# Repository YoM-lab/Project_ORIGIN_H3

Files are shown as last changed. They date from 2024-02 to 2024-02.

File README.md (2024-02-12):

## Project-ORIGIN_H3


## 项目简介
> 小up是一个开发板兴趣爱好者:-)，市面上绝大部分Linux开发板都是没有小巧屏幕的，而且设计闭源不能随心所欲的更改，只是买回来玩并不能深刻理解，引用费曼所说：“What I cannot create，I do not understand”，结合网上的开源方案，所以就有了想自己制作的想法，一来是想熟悉Allegro软件，二来是巩固Linux驱动开发。现在发布出来供后来人参考，同时也参考一些开源社区和UP主，后面会一一列出。硬件在23年5月份完成，由于up是一个学生，制作过程全部自费，所以采用了四层板，对于初学者走线非常痛苦:-(；软件在23年9月份完成，由于研二阶段太忙了，一直到现在才正式发出来:-)
>
> 项目在硬件上包括了1.14寸显示屏、麦克风、音频、HDMI、WIFI、MIPI摄像头(未驱动成功，非必须)，基本上可以实现一个卡片电脑的功能。

**项目制作流程**：[【自制】开源四核A7卡片电脑，从规划到实物软硬件开发，拥有自己的小电脑](https://www.bilibili.com/video/BV1XW421P7bK/?share_source=copy_web&vd_source=7833e202419e0abc2ac3d27a5c3fbd21)

## 硬件部分

* 硬件设计全部在**1_Hardware**文件夹
* 设计使用的**软件是Allegro，而不是AD！！！**在**1_Hardware**文件夹内给出了原理图
* 焊接使用了**加热台、热风枪、低温焊锡膏、钢网**
* 由于up只进行了一次打板（自费），在后期难免的遇到了一些问题，大部分都是因为板层不够多（四层）导致的，**但不影响第一板的正常运行**。up时间有限，未能作出更改，如果有后来者复刻，可以上六层板，进一步缩小体积，方便布线，项目硬件上可改进之处参考**1_Hardware/README.md**文件
## 软件部分

* **Uboot**
	
	* 在**2_Uboot**文件夹内
	* Uboot适配的是全志官方支线，没有做出太多修改
* **Linux**
	* 在**3_Linux**文件夹内
	* 内核是自己适配4.14.111内核，也可采用第三方内核（国内开发板厂商）
* **Rootfs** 
	* 在**4_Rootfs**文件夹内
	
	* 根文件系统是自己移植的ubuntu16.04， 也可采用第三方根文件系统（国内开发板厂商）
* 编译方法可以参考教程：[Building U-boot and Linux for H5/H3/H2+/zh - FriendlyELEC WiKi](https://wiki.friendlyelec.com/wiki/index.php/Building_U-boot_and_Linux_for_H5/H3/H2+/zh)
* 由于Github不能上传大文件，所以请大家通过百度云下载:-(

## 烧录镜像
* 烧录SD镜像在**5_Images**文件夹内
* Ubuntu16.04为个人制作的镜像，用户名：pi，密码：pi，root密码：oh3
* Debian 8为第三方镜像，参考连接：[NanoPi M1 Plus/zh - FriendlyELEC WiKi](https://wiki.friendlyelec.com/wiki/index.php/NanoPi_M1_Plus/zh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)
## 驱动部分

* Linux简单的驱动移植在7_Drivers文件夹内，在up本人学习时编写的，把ORIGIN_H3当成一个小型的开发板:-)
* MPU6050驱动在21_I2C文件夹内
* 驱动编写参考：[i.MX6ULL Linux阿尔法开发板 — 正点原子资料下载中心 1.0.0 文档 (openedv.com)](http://www.openedv.com/docs/boards/arm-linux/zdyz-i.mx6ull.html)

## 参考链接

* [NanoPi M1 Plus/zh - FriendlyELEC WiKi](https://wiki.friendlyelec.com/wiki/index.php/NanoPi_M1_Plus/zh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)
* [orangepi-xunlong (Orange Pi) (github.com)](https://github.com/orangepi-xunlong)
*  [OSHW\] Yuzuki Chameleon is a Raspberry Pi A Shaped SBC based on Allwinner H616 (github.com)](https://github.com/YuzukiHD/YuzukiChameleon)
* [peng-zhihui/Project-Quantum: 超迷你模块化卡片电脑计划 (github.com)](https://github.com/peng-zhihui/Project-Quantum)
* [小白自制Linux开发板(F1C200s)整理系列，持续更新中 / 全志 SOC / WhyCan Forum(哇酷开发者社区)](https://whycan.com/t_7275.html)
* [i.MX6ULL Linux阿尔法开发板 — 正点原子资料下载中心 1.0.0 文档 (openedv.com)](http://www.openedv.com/docs/boards/arm-linux/zdyz-i.mx6ull.html)

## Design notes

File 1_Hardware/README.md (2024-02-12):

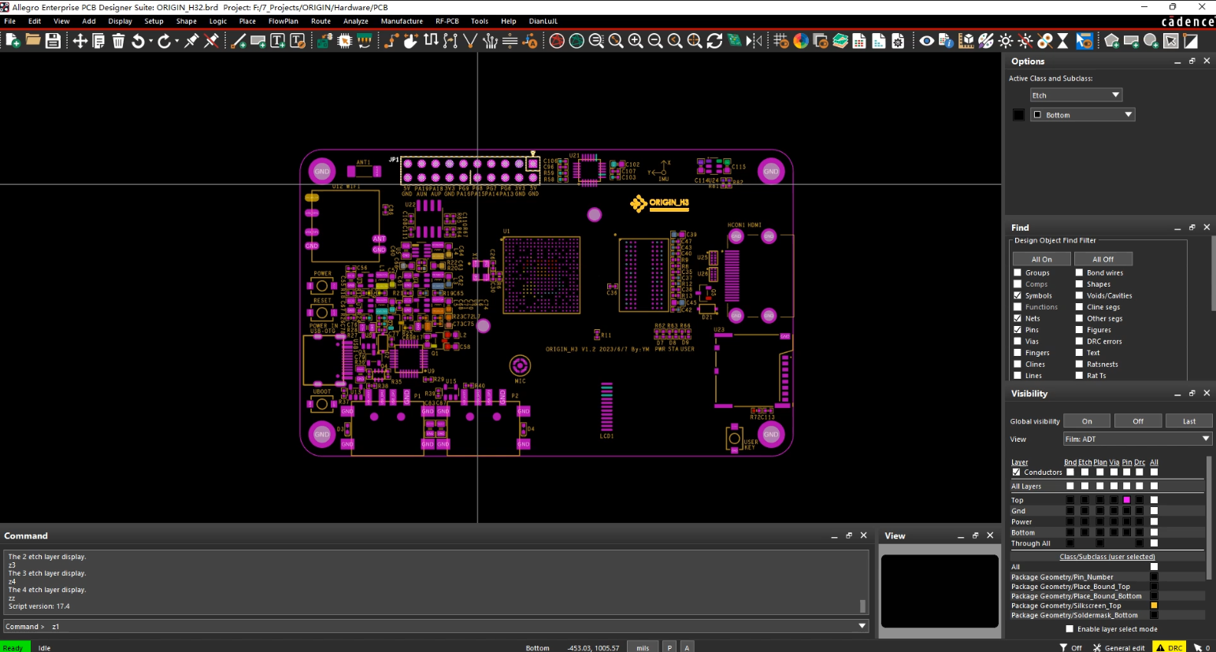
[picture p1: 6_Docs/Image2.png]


## ORIGIN_H3

* 硬件采用Allegro软件设计(Capture CIS 17.4 + PCB Editor 17.4)，使用相同及以上版本即可打开。
## Garber文件
* 电路板打样需要使用到Garber文件，已经导出在__ORIGIN_H3_Garber.rar__文件内。
## Allegro软件安装参考
[阿狸狗破戒大师 | 吴川斌的博客 (mr-wu.cn)](http://aligou.mr-wu.cn/)。
## 硬件优化
由于up只进行了一次打板（自费），在后期难免的遇到了一些问题，大部分都是因为板层不够多（四层）导致的，**但不影响第一板的正常运行**。up时间有限，未能作出更改，如果有后来者复刻，可以上六层板，进一步缩小体积，方便布线，项目硬件上可改进之处列在下面：
  * IMU丝印错误
  * USB封装有误
  * HDMI未进行等长布线
  * 摄像头接口电路有误（视频中使用的是USB摄像头）
  * MIC走线未包地处理
  * 音频输出电路走线未包地处理
  * 丝印C44和C41电容接触过近
  * 原理图中U13、U14芯片SY6280为USB限流芯片，可以直接将EN引脚接VCC，若未修改直接打板，需要使用磁阻或0欧姆电阻直接将输入和输出短接：


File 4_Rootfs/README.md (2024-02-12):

## ORIGIN_H3-Rootfs

## Ubuntu 16.04

* 系统打包成SD卡烧录镜像教程参考：[friendlyarm/sd-fuse_h3 (github.com)](https://github.com/friendlyarm/sd-fuse_h3)

* 百度云下载地址：

  链接：https://pan.baidu.com/s/1aDvAWxIi5sTljFk5ktj55g?pwd=2j3l 
  提取码：2j3l

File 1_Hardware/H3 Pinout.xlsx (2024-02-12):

PIN | Function |  | PIN | Function |  |  | PIN | PIN |  |  | PIN | Function |  | PIN |  |  | PIN
PA0 | UART2_TX | UART2 | PC0 | SPI0_MOSI | LCD_SDA | LCD | PD0 | PE0 | CAM | CAM | PF0 | SDC0_D1 | TF | PG0 |  |  | PL0
PA1 | UART2_RX |  | PC1 |  |  |  | PD1 | PE1 | CAM |  | PF1 | SDC0_D0 |  | PG1 |  |  | PL1
PA2 |  |  | PC2 | SPI0_CLK | LCD_SCL |  | PD2 | PE2 | CAM |  | PF2 | SDC0_CLK |  | PG2 | KYE | KEY | PL2
PA3 |  |  | PC3 | SPI0_CS | LCD_CS |  | PD3 | PE3 | CAM |  | PF3 | SDC0_CMD |  | PG3 | KEY |  | PL3
PA4 | UART0_TX | DEBUG | PC4 | I/O | LCD_RS |  | PD4 | PE4 | CAM |  | PF4 | SDC0_D3 |  | PG4 | KEY |  | PL4 | GPIO | RECOVERY
PA5 | UART0_RX |  | PC5 | I/O | LCD_RES |  | PD5 | PE5 | CAM |  | PF5 | SDC0_D2 |  | PG5 |  |  | PL5 | GPIO | VCC-IO-EN
PA6 |  |  | PC6 |  |  |  | PD6 | PE6 | CAM |  | PF6 | SDC0_DET |  | PG6 | UART1_TX | UART | PL6
PA7 |  |  | PC7 |  |  |  | PD7 | PE7 | CAM |  |  |  |  | PG7 | UART1_RX |  | PL7 | GPIO | WIFI_EN
PA8 | MPU6050-INT | MPU6050 | PC8 |  |  |  | PD8 | PE8 | CAM |  |  |  |  | PG8 | UART1_RTS |  | PL8 | GIPO | PWR_STB
PA9 | USER | LED | PC9 |  |  |  | PD9 | PE9 | CAM |  |  |  |  | PG9 | UART1_CTS |  | PL9 | GPIO | PWR_DRAM
PA10 | STATUS |  | PC10 |  |  |  | PD10 | PE10 | CAM |  |  |  |  | PG10 |  |  | PL10 | GPIO | PWR_LED
PA11 | I2C_SCK | MPU6050 | PC11 |  |  |  | PD11 | PE11 | CAM |  |  |  |  | PG11 |  |  | PL11
PA12 | I2C_SDA |  | PC12 |  |  |  | PD12 | PE12 | CAM |  |  |  |  | PG12 | PG12/USB0-OTGID | OTG
PA13 | SPI1_CS | SPI1 | PC13 |  |  |  | PD13 | PE13 | CAM |  |  |  |  | PG13
PA14 | SPI1_CLK |  | PC14 |  |  |  | PD14 | PE14 | GPIO
PA15 | SPI1_MOSI |  | PC15 |  |  |  | PD15 | PE15 | GPIO
PA16 | SPI1_MISO |  | PC16 |  |  |  | PD16
PA17 |  |  |  |  |  |  | PD17
PA18 | I2C_SCK | I2C1
PA19 | I2C_SDA
PA20
PA21
DRAM | LPDDR3 |  | HDMI | HDMI
USB0 | OTG |  | AUDIO | MIC | LINEOUT
USB1 | WIFI
USB2 | USB |  | RESET | RESET
USB3 | USB
 |  |  | UBOOT | UBOOT
 |  |  | CRYSTAL | CRYSTAL

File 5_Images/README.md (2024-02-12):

## ORIGIN_H3-Images

## Ubuntu 16.04

链接：https://pan.baidu.com/s/1Oyq-yipzldtNqOIcfeMQRg?pwd=ue1q 
提取码：ue1q 

## Debian

链接：https://pan.baidu.com/s/198FMZw4U8keiZBAOxm9Zbw?pwd=ifme 
提取码：ifme

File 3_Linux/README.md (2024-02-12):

## ORIGIN_H3-Linux

* 编译方法可以参考Friendlyelec的教程：[Building U-boot and Linux for H5/H3/H2+/zh - FriendlyELEC WiKi](https://wiki.friendlyelec.com/wiki/index.php/Building_U-boot_and_Linux_for_H5/H3/H2+/zh)

* 百度云下载地址：

  链接：https://pan.baidu.com/s/18vKWBYgACM9pWhj-3_hcDg?pwd=lwhe 
  提取码：lwhe

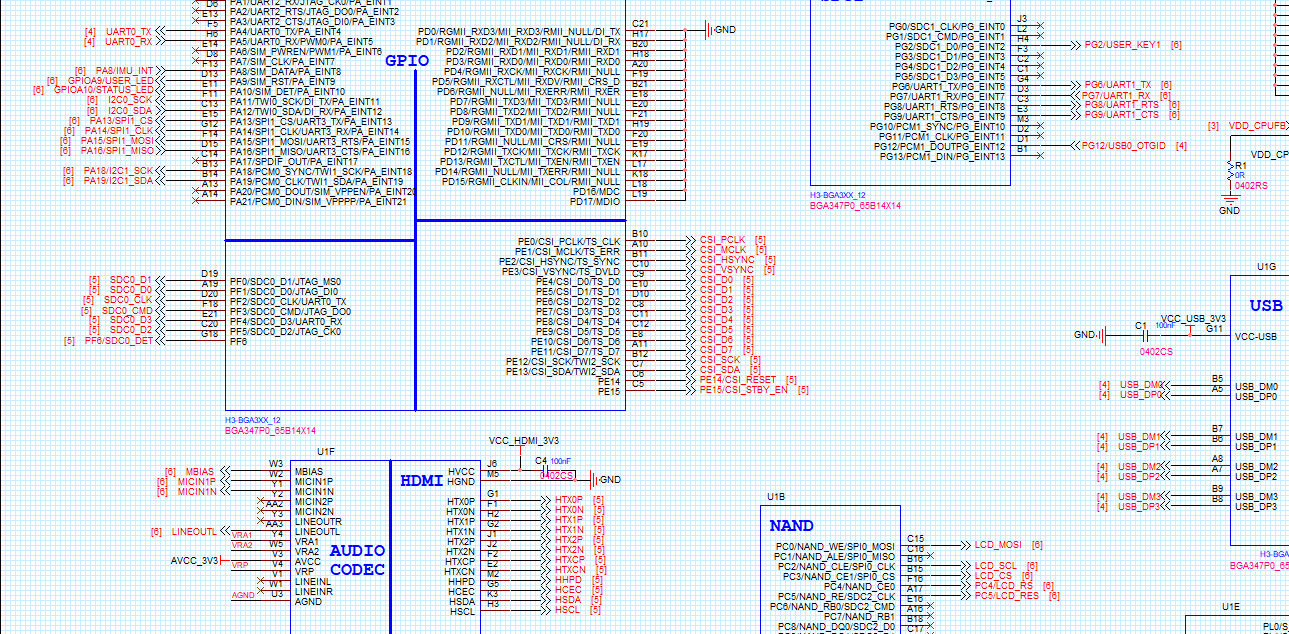
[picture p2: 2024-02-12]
1_Hardware/ORIGIN_H3.png

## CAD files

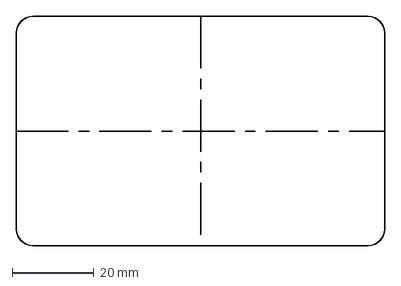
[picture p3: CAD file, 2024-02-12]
1_Hardware/origin_outline.DXF
90.0 x 56.0 mm

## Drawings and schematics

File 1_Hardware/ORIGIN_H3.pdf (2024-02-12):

# CPU

# GPIO

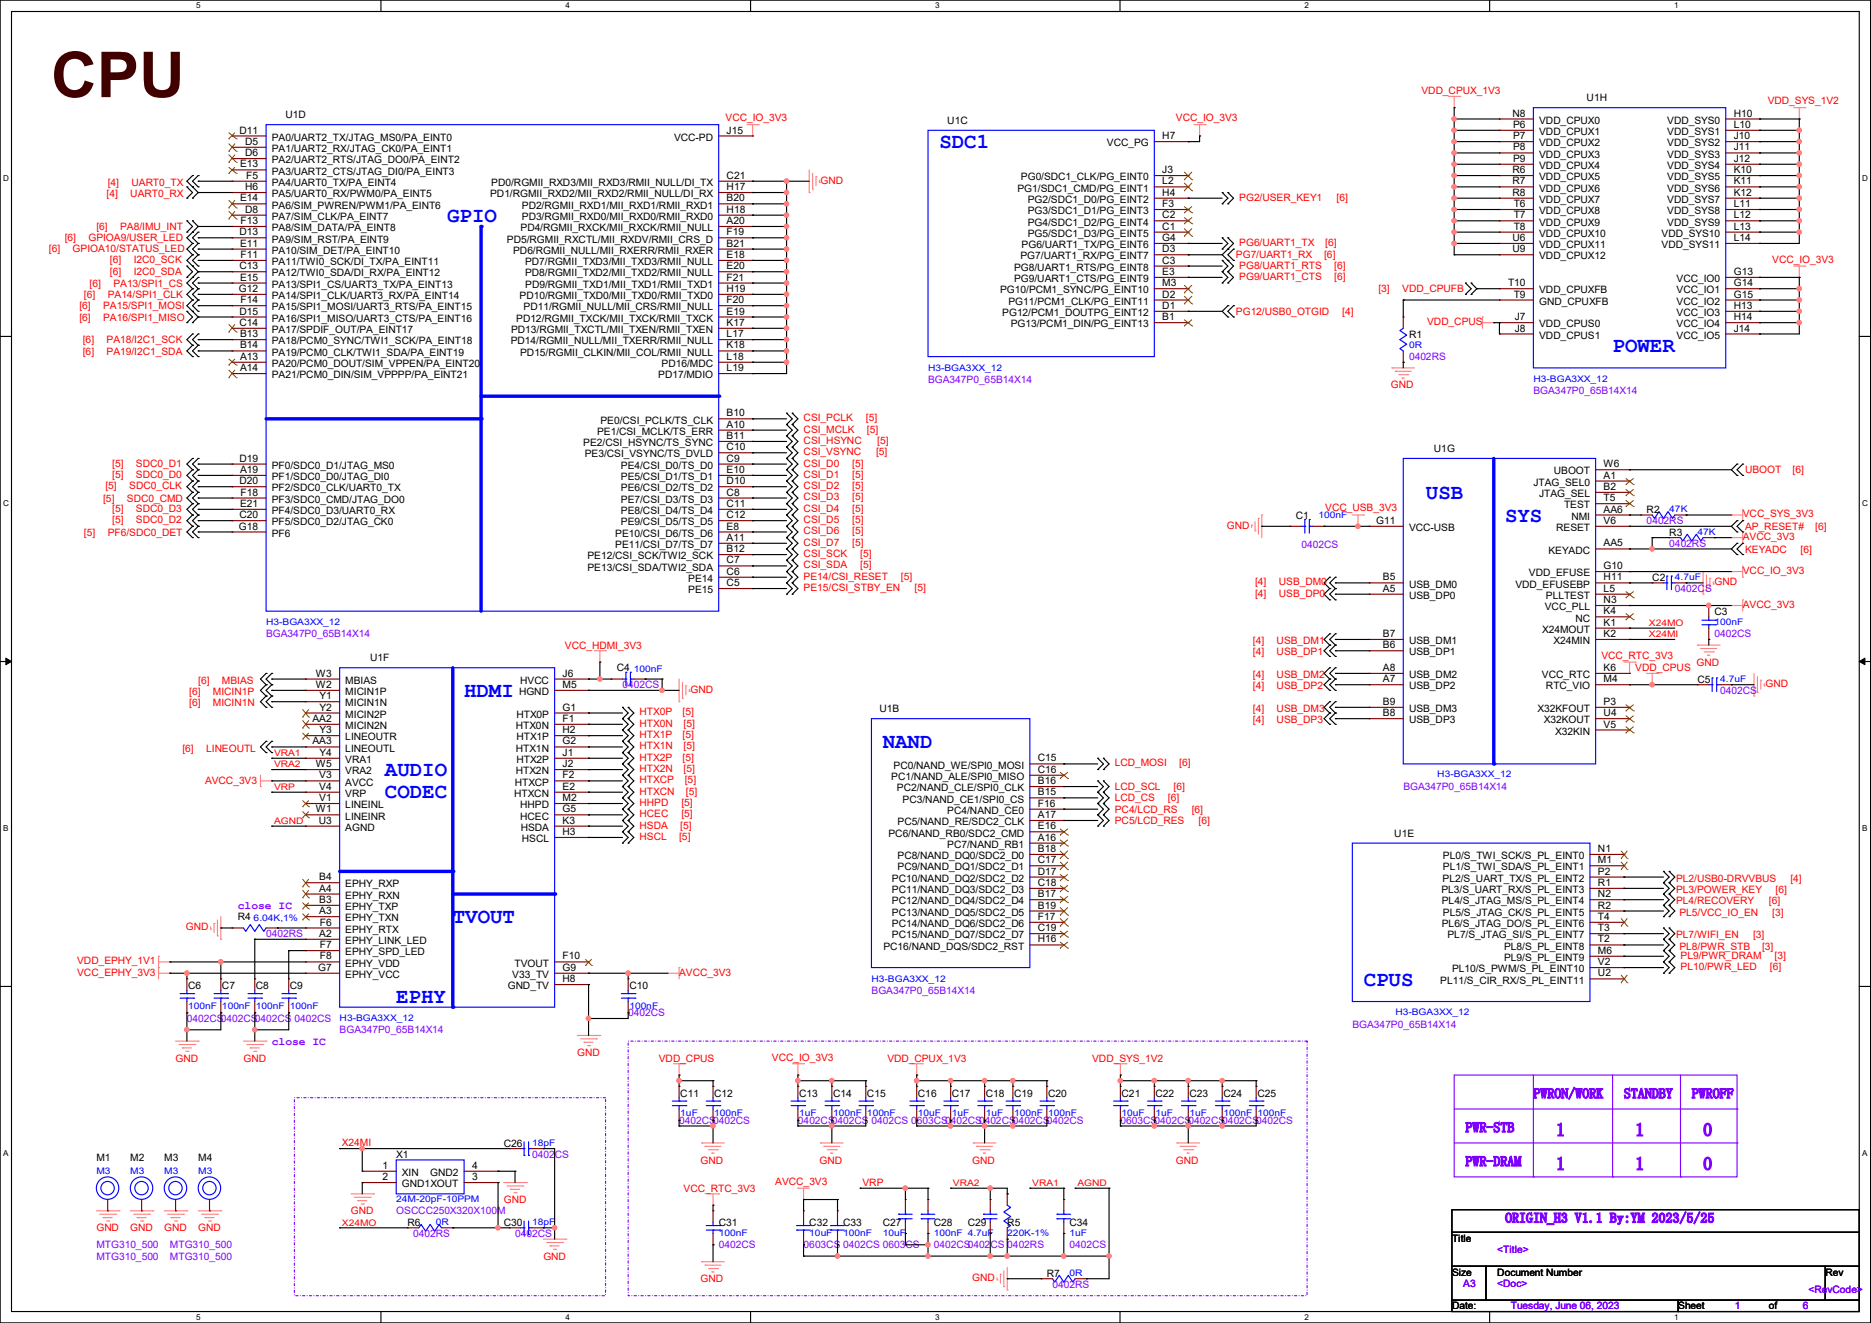
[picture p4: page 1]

# DDR3 16×1

# DRAM

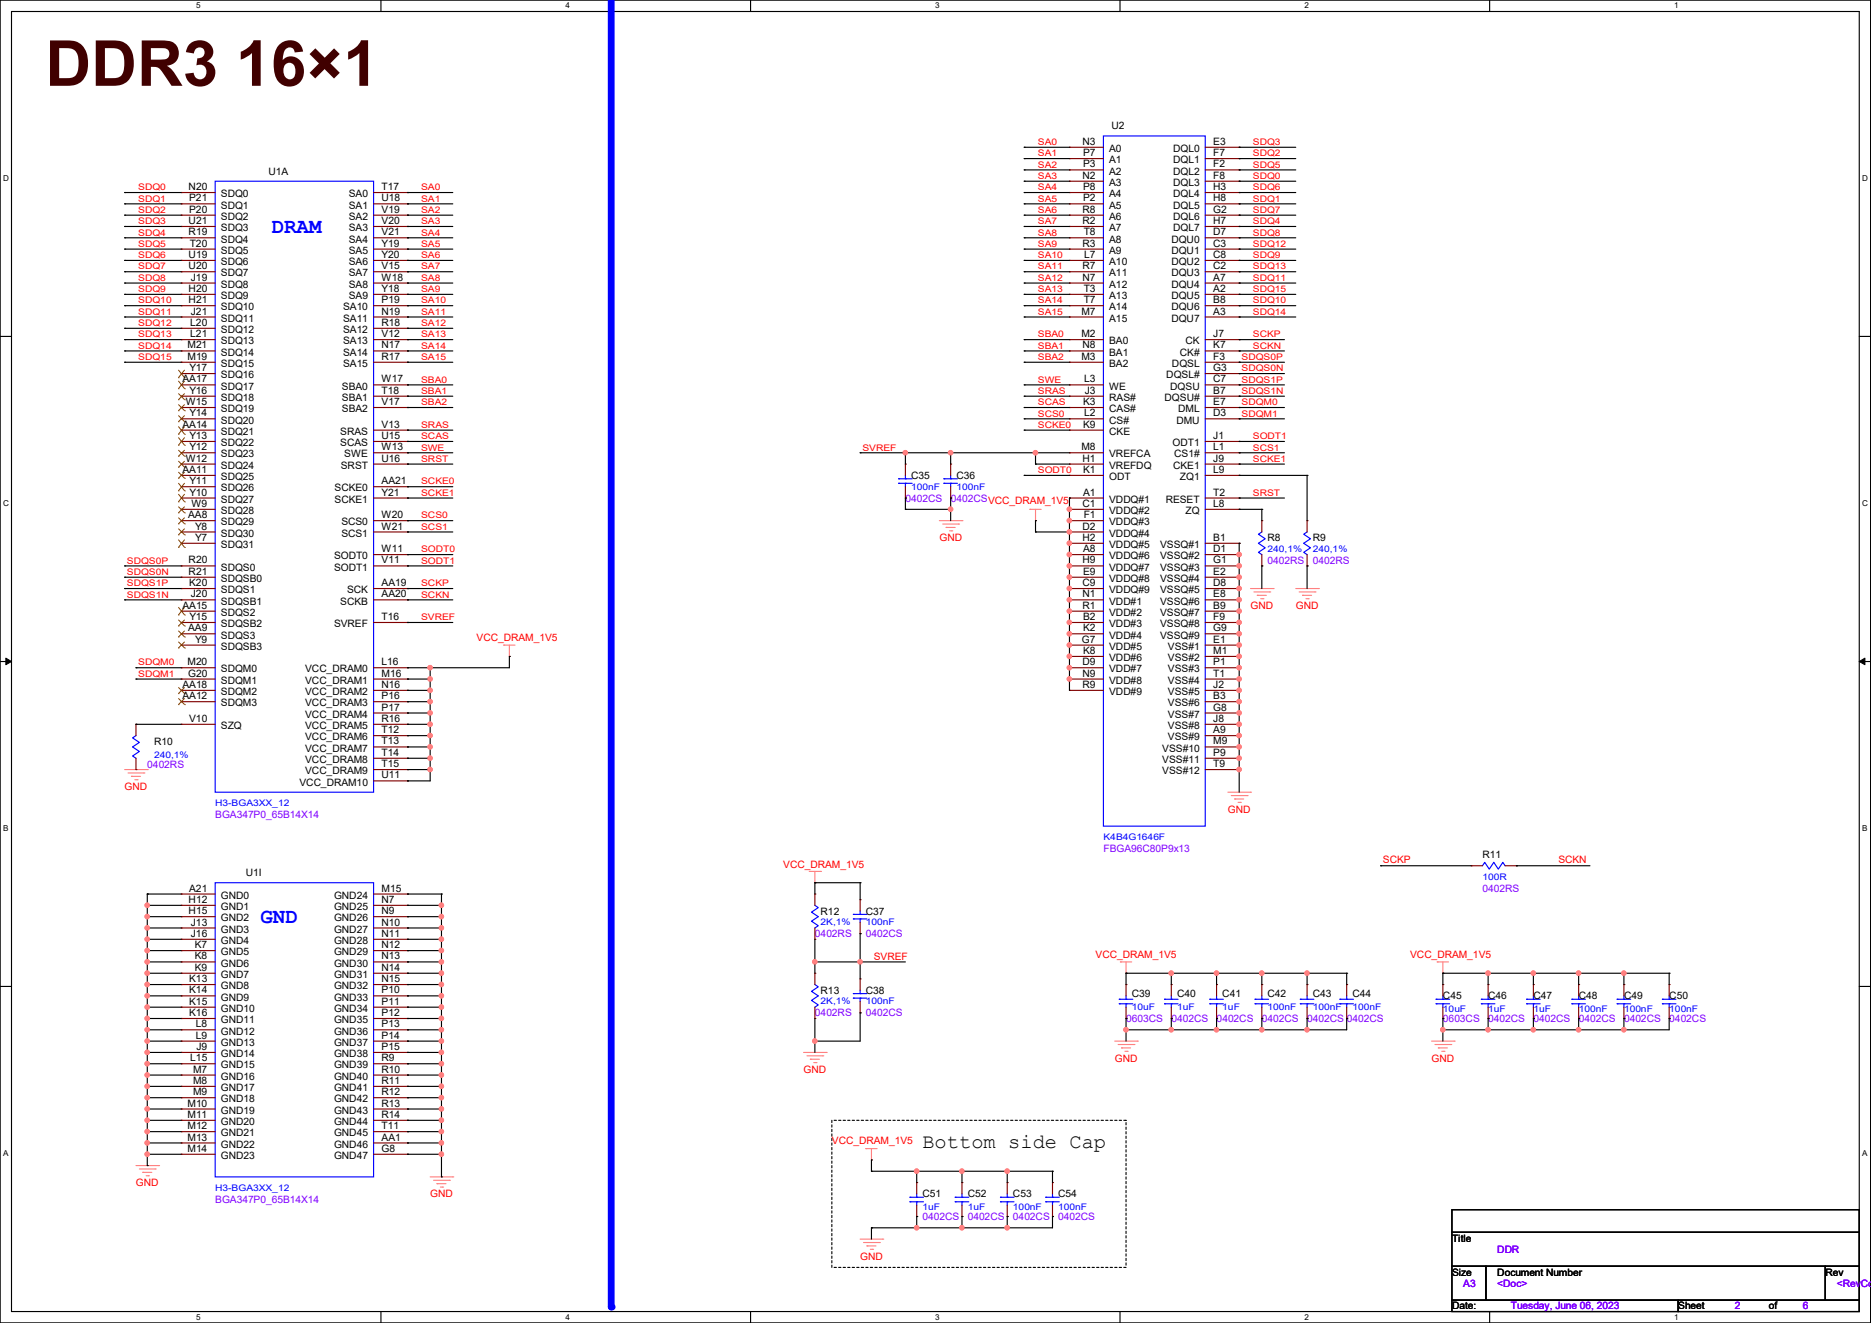
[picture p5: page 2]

3.3V/1A

# POWER

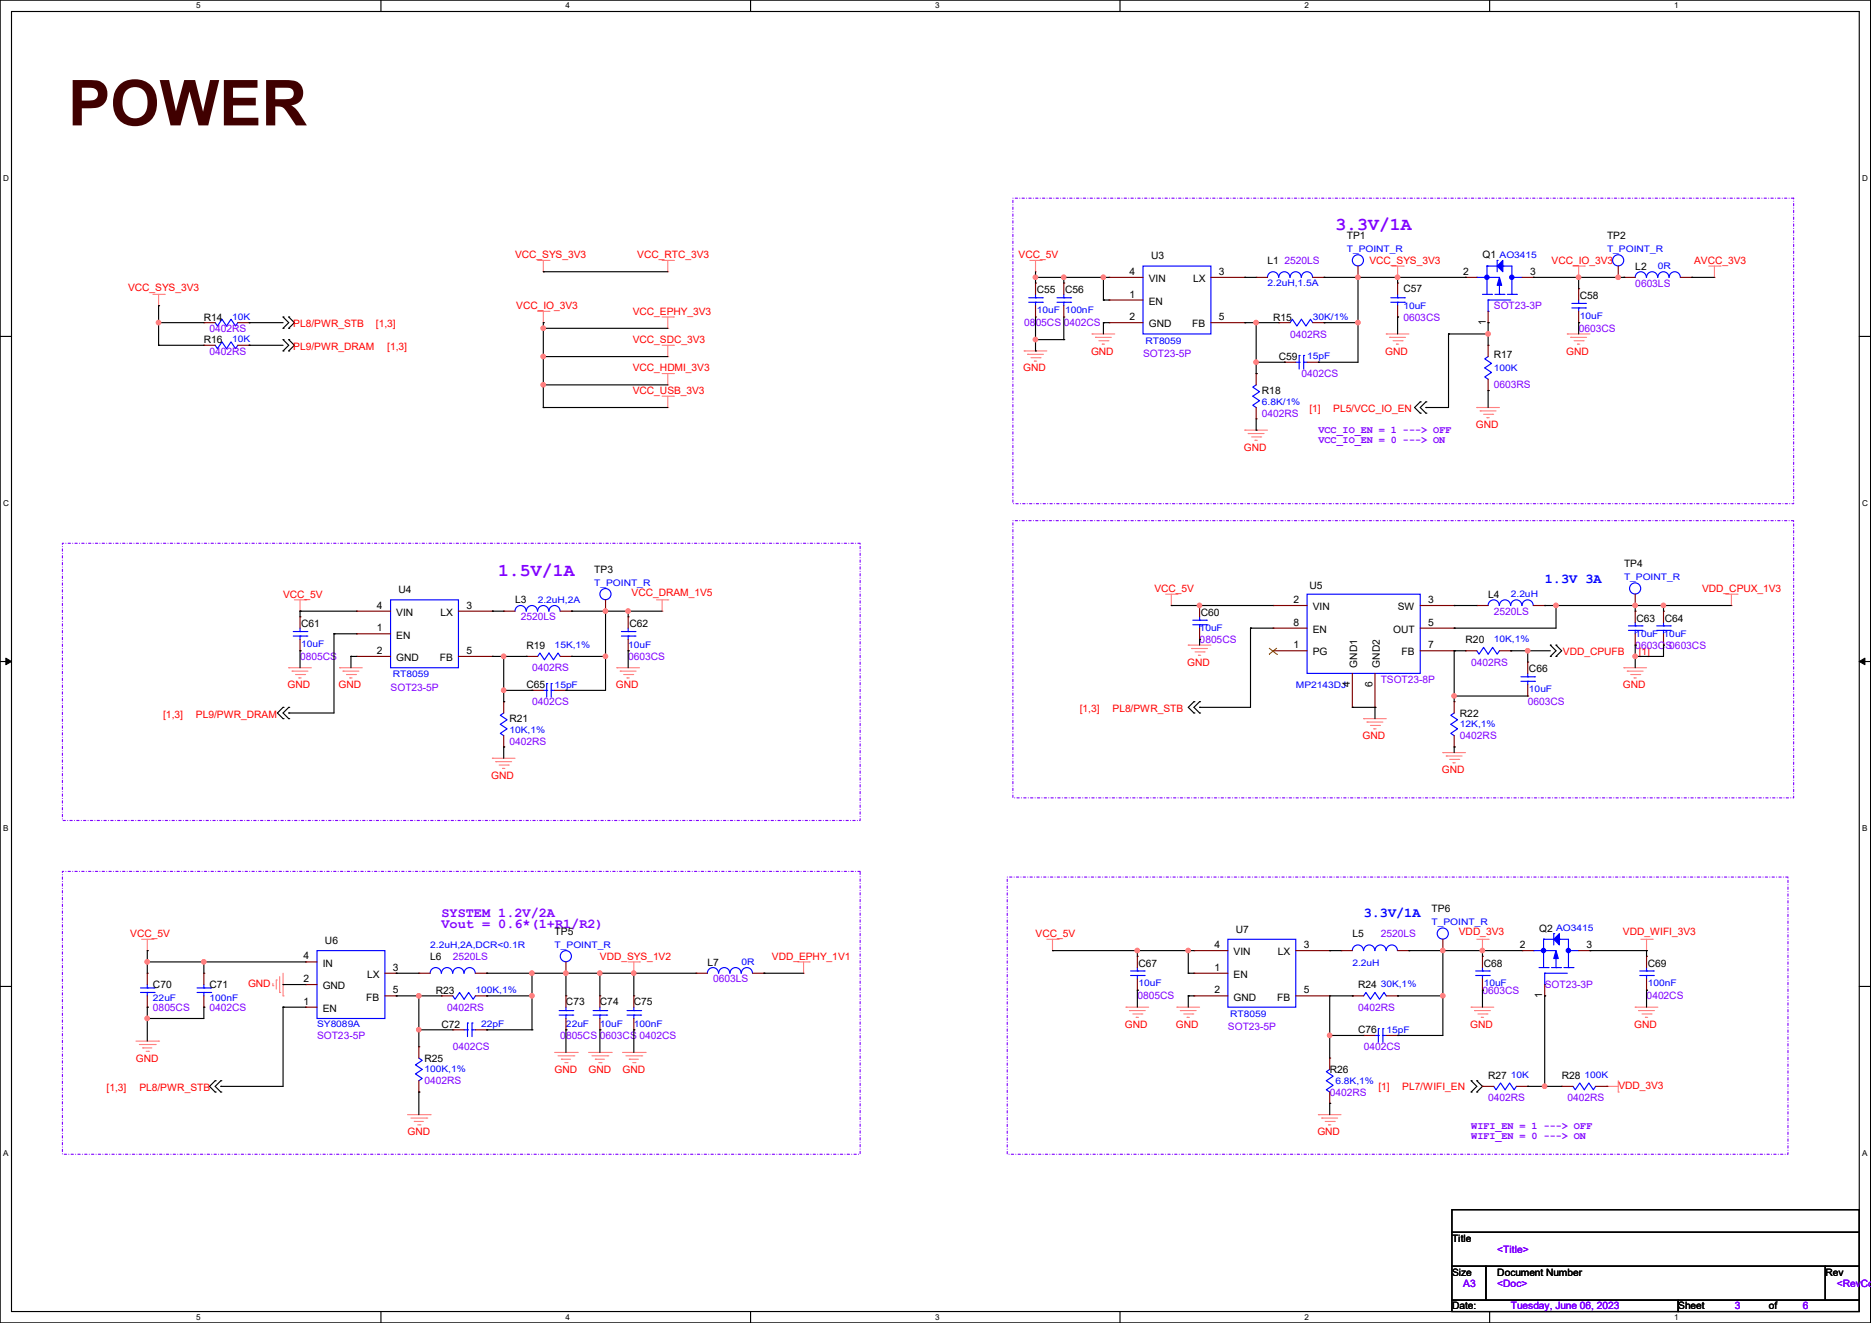
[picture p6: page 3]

# USB-UART-WIFI

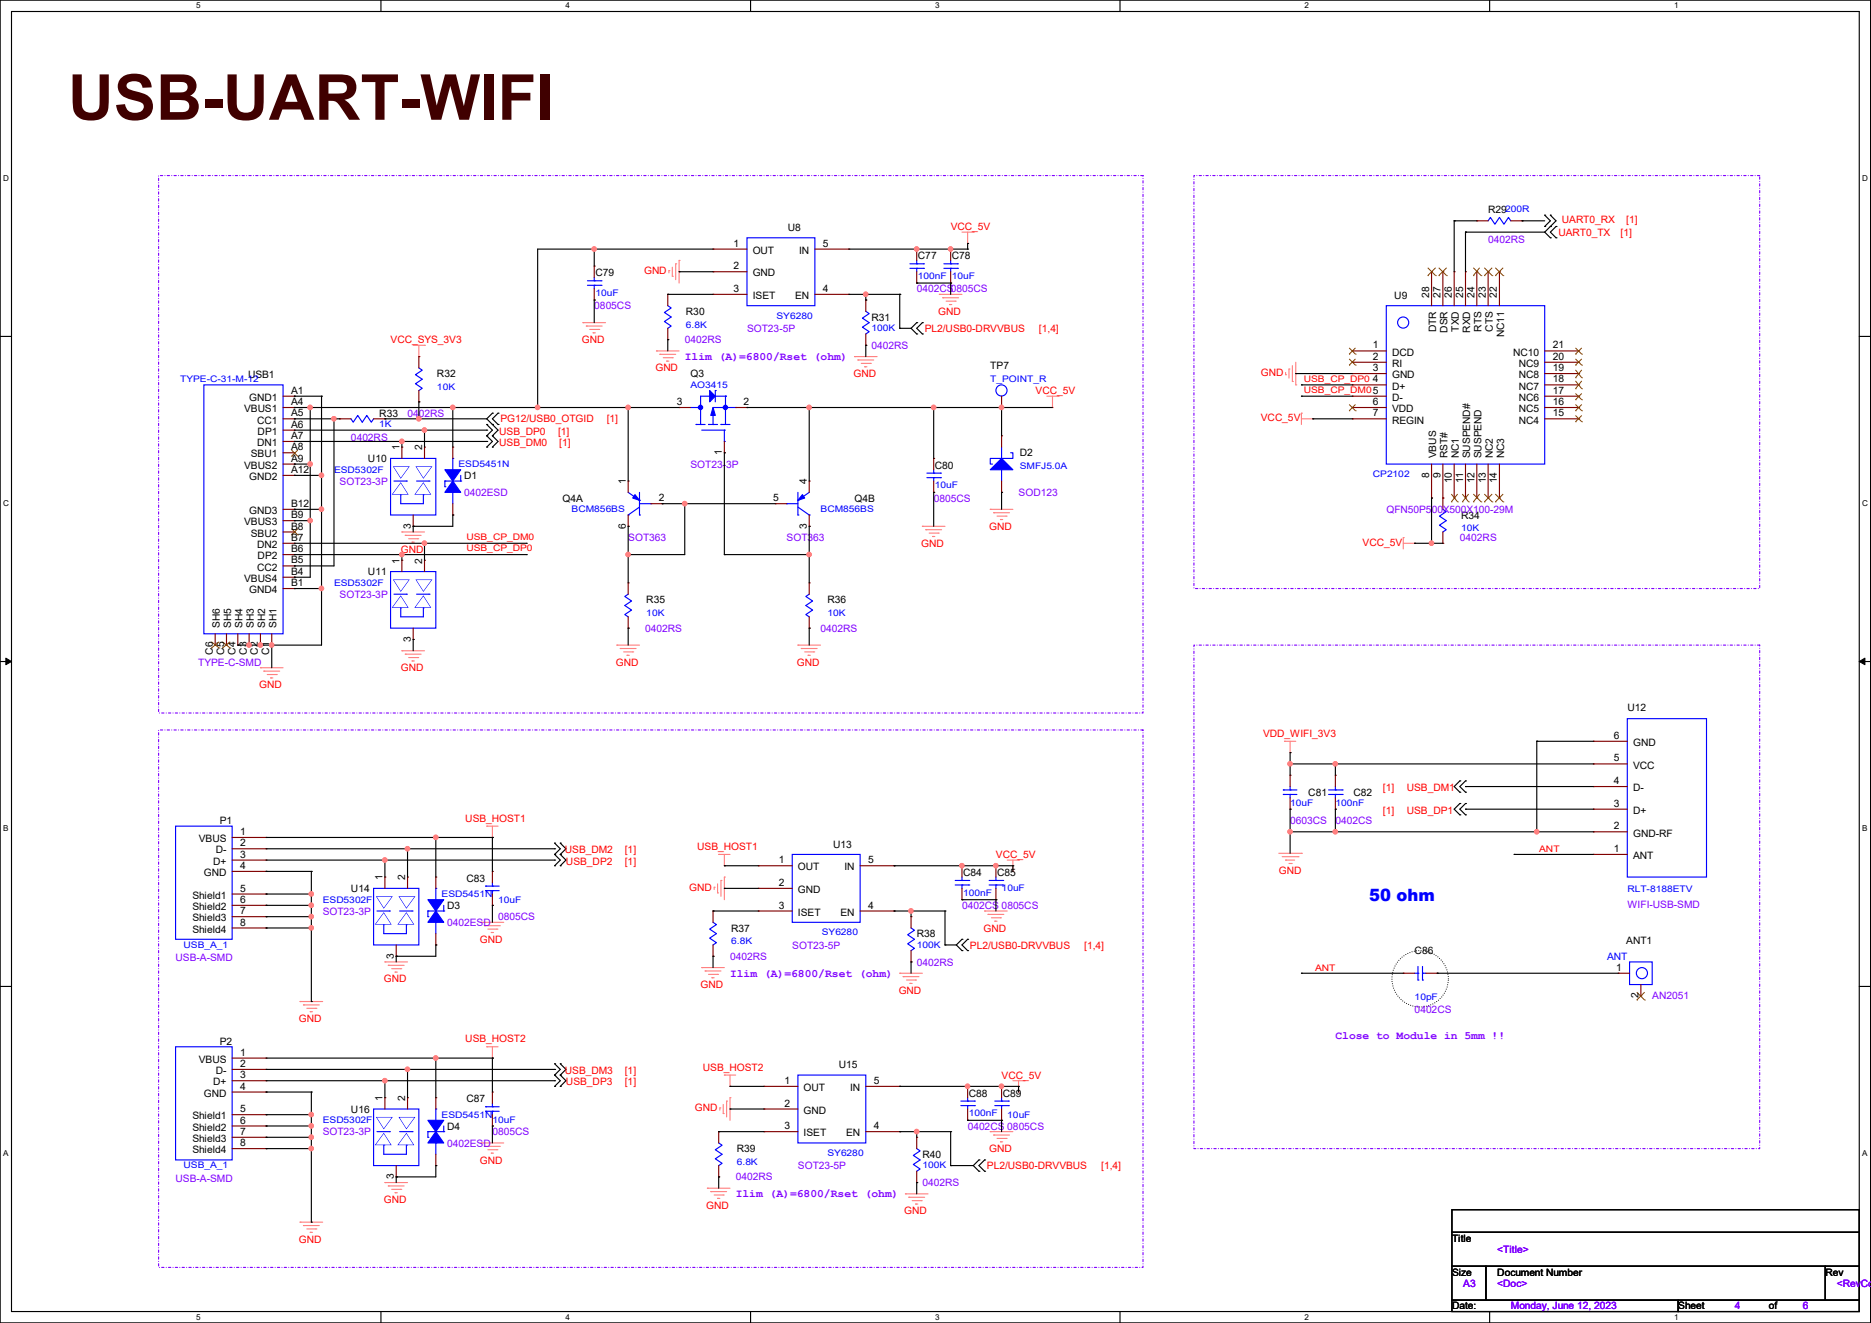
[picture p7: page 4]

NC11 22 CTS 23 RTS 24 RXD 25 TXD 26 DSR 27 DTR 28

GND4 B1 SH¹ C¹ SH² C² SH³ C³ SH⁴ C⁴ SH⁵ C⁵ SH⁶ C⁶

Close to Module in 5mm !!

# TF-CAM-HDMI

1 1 2 2 3 3 4 4 5 5 6 6 7 7 8 8 9 9 10 10 11 11 12 12 13 13 14 14 15 15 16 16 17 17 18 18 19 19 20 20 21 21 22 22 23 23 24 24

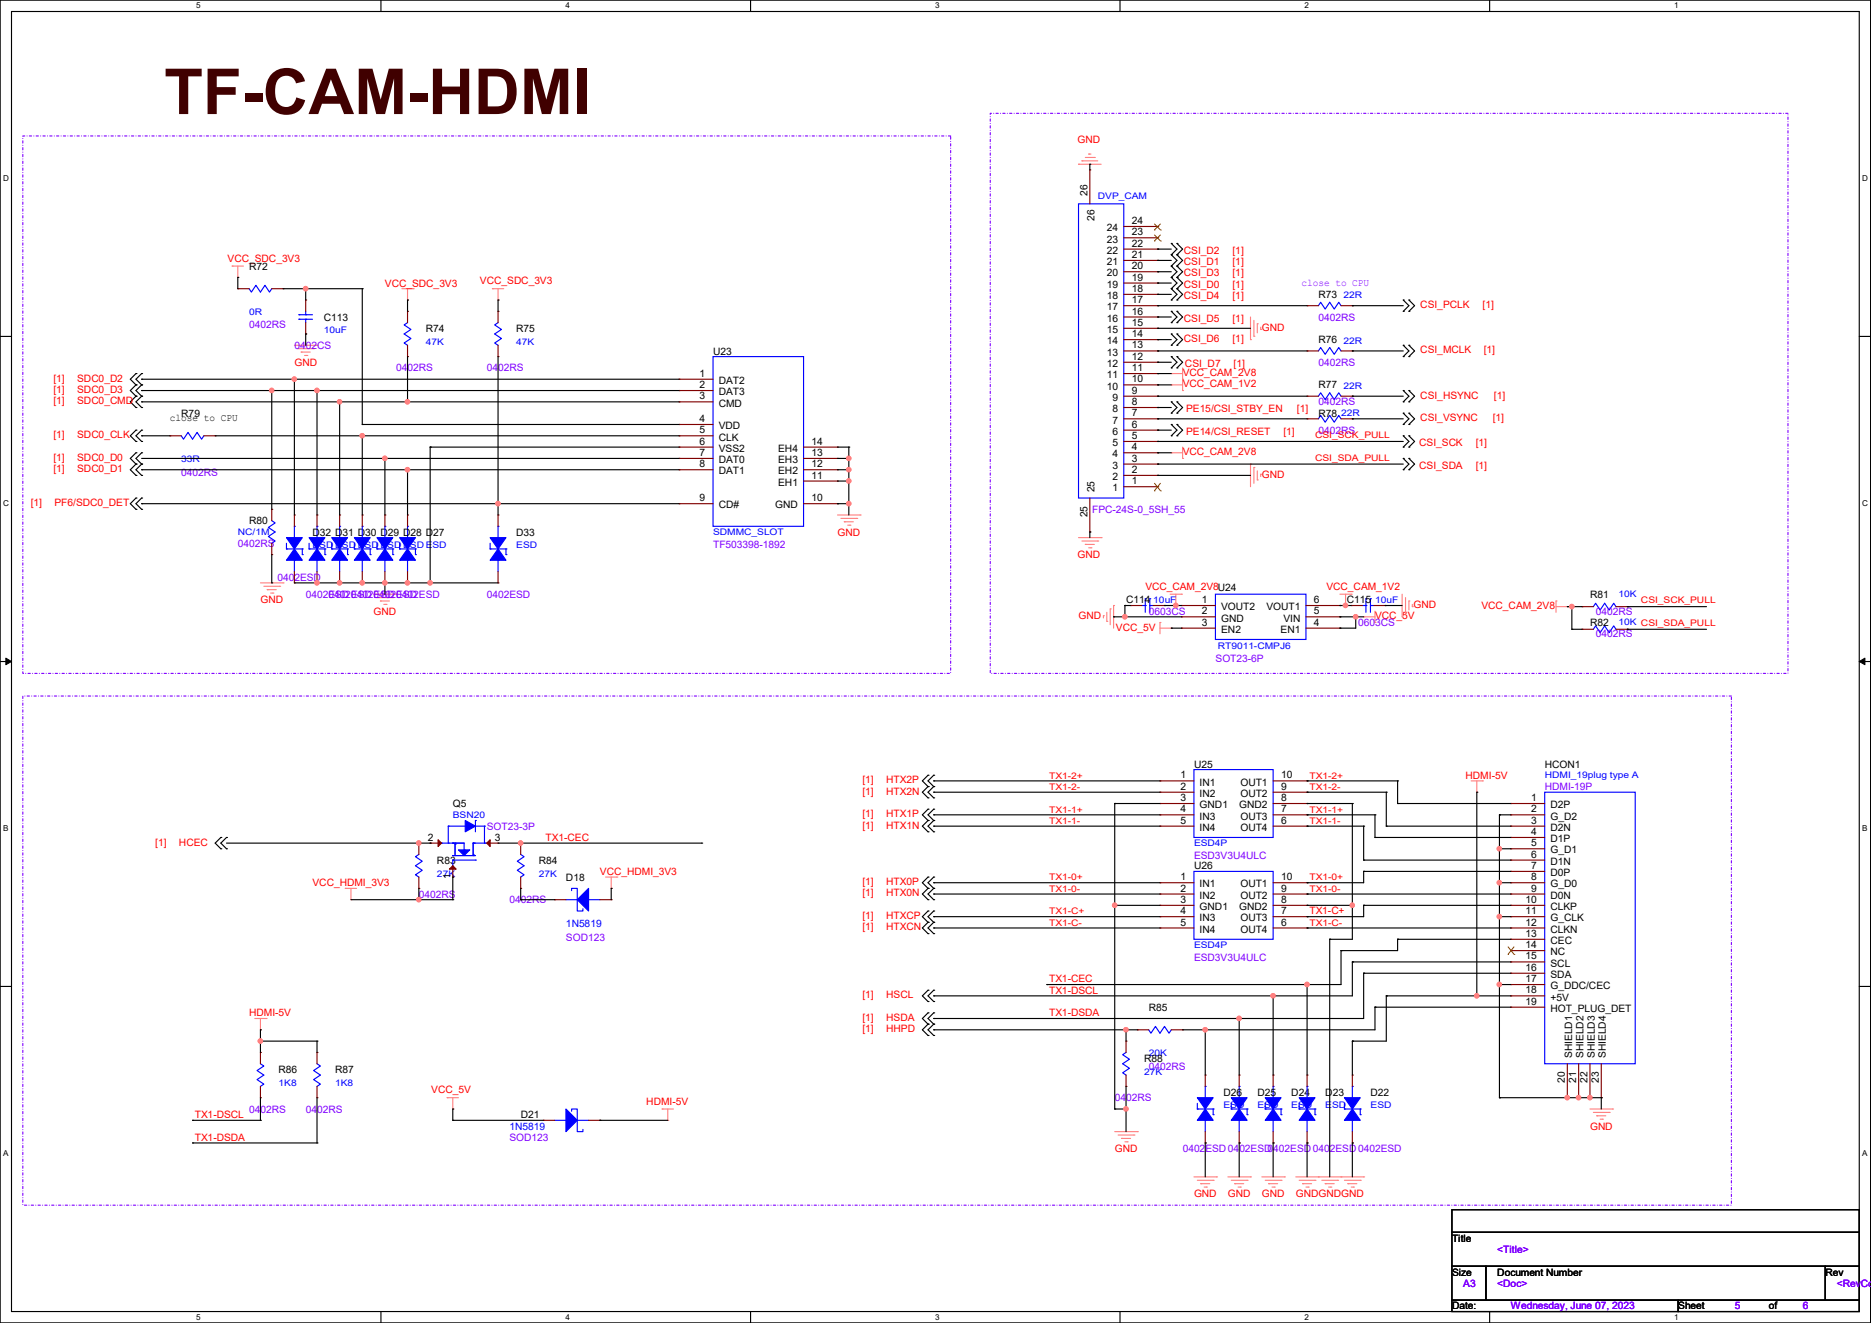
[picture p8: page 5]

GND GND GND GNDGNDGND

# IMI-LCD-MIC-OTHERS

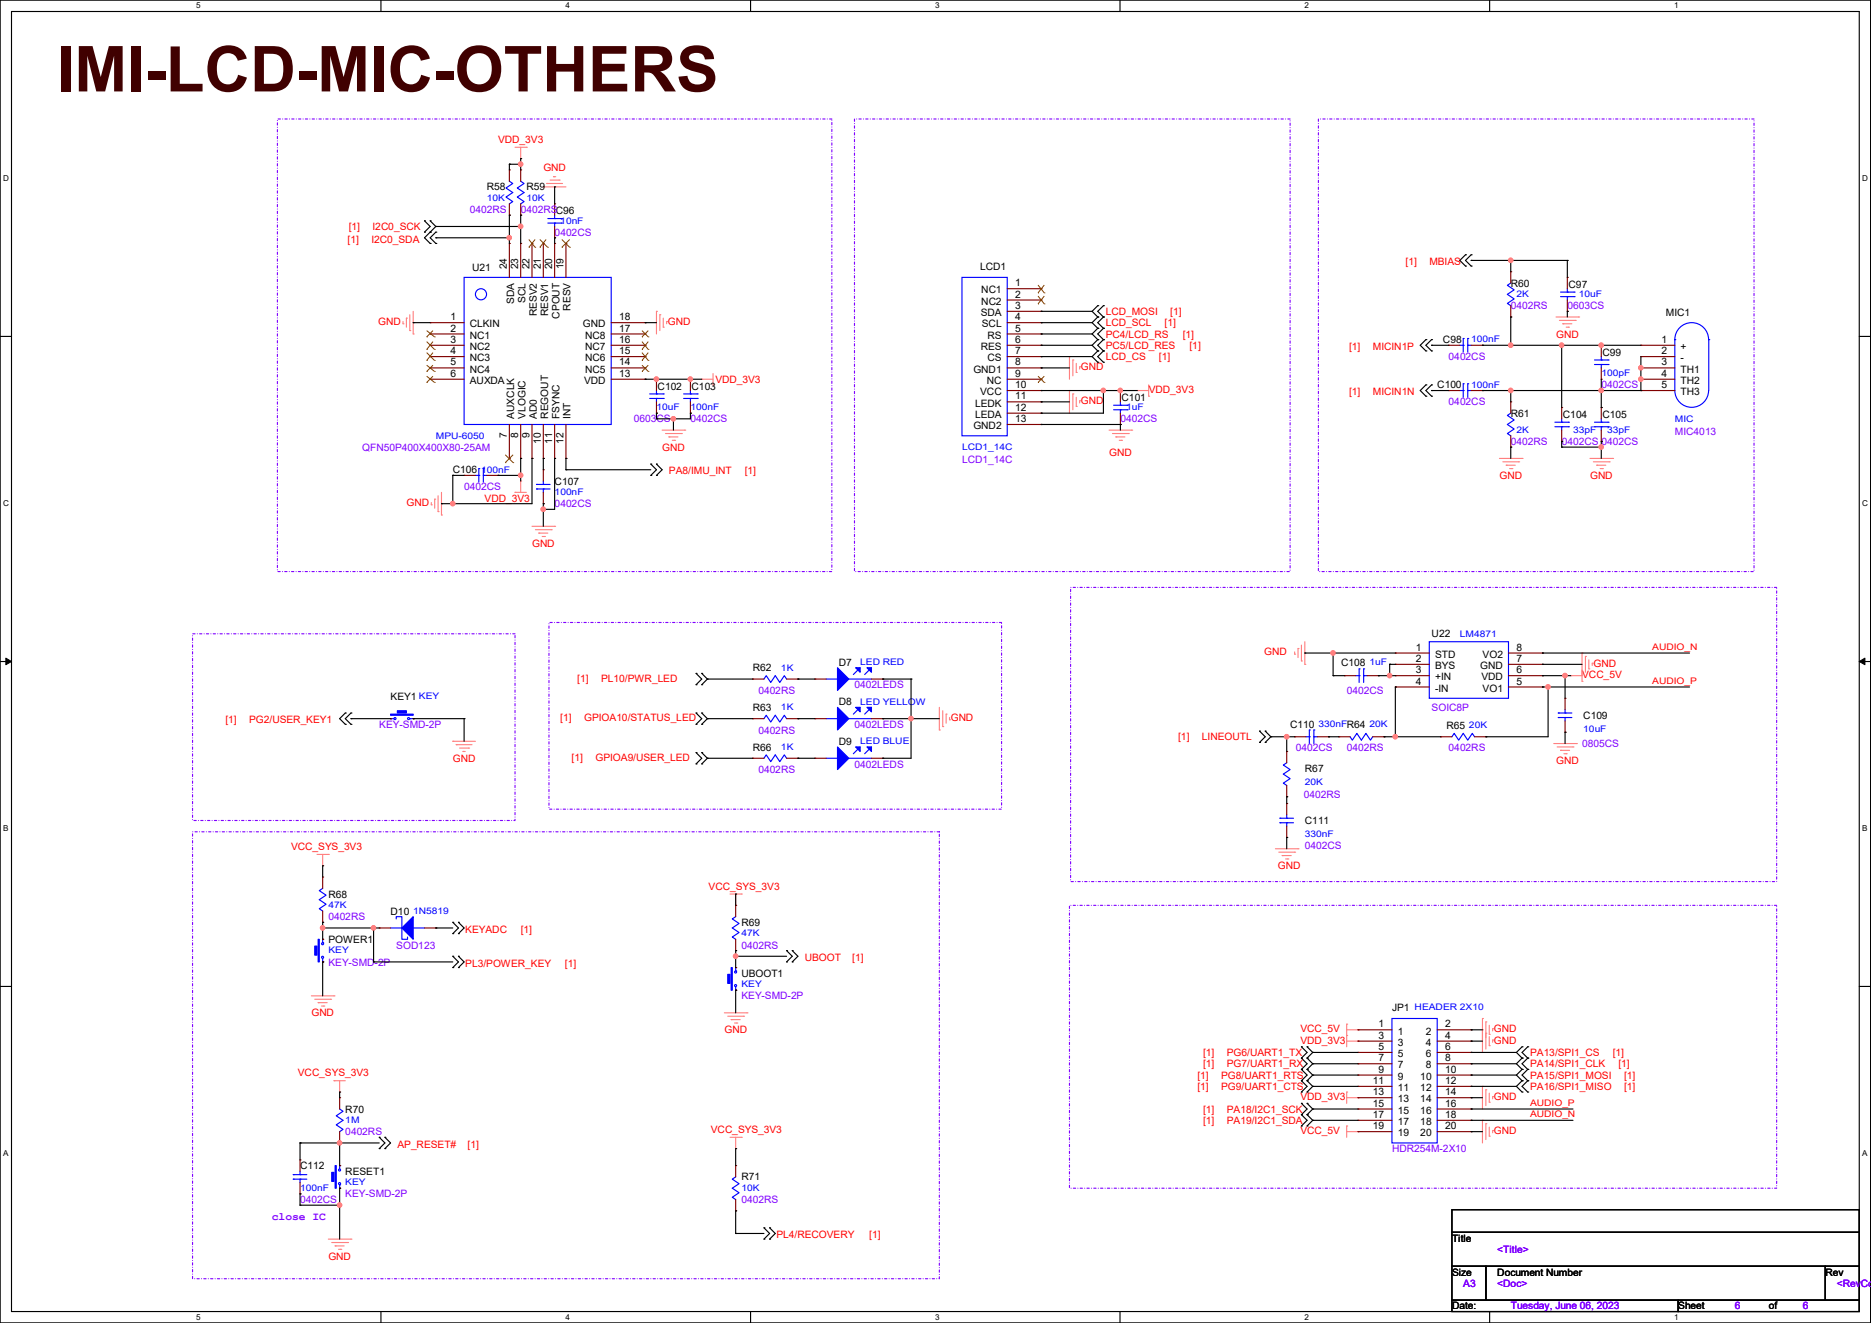
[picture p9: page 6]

RESV 19 CPOUT 20 RESV1 21 RESV2 22 SCL 23 SDA 24

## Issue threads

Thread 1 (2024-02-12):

请问有原理图吗，想看看音频部分

LMNB66, 2024-02-12:
请问有原理图吗，想看看音频部分

YoM-lab, 2024-02-12:
好的，附件是原理图，后面会更新至github仓库内

游孟
***@***.***

&nbsp;

------------------&nbsp;原始邮件&nbsp;------------------
发件人:                                                                                                                        "YoM-lab/Project_ORIGIN_H3"                                                                                    ***@***.***&gt;;
发送时间:&nbsp;2024年2月12日(星期一) 晚上7:15
***@***.***&gt;;
***@***.***&gt;;
主题:&nbsp;[YoM-lab/Project_ORIGIN_H3] 请问有原理图吗，想看看音频部分 (Issue #1)

请问有原理图吗，想看看音频部分

—
Reply to this email directly, view it on GitHub, or unsubscribe.
You are receiving this because you are subscribed to this thread.Message ID: ***@***.***&gt;
